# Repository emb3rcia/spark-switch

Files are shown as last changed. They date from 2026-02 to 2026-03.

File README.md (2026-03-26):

# spark-switch

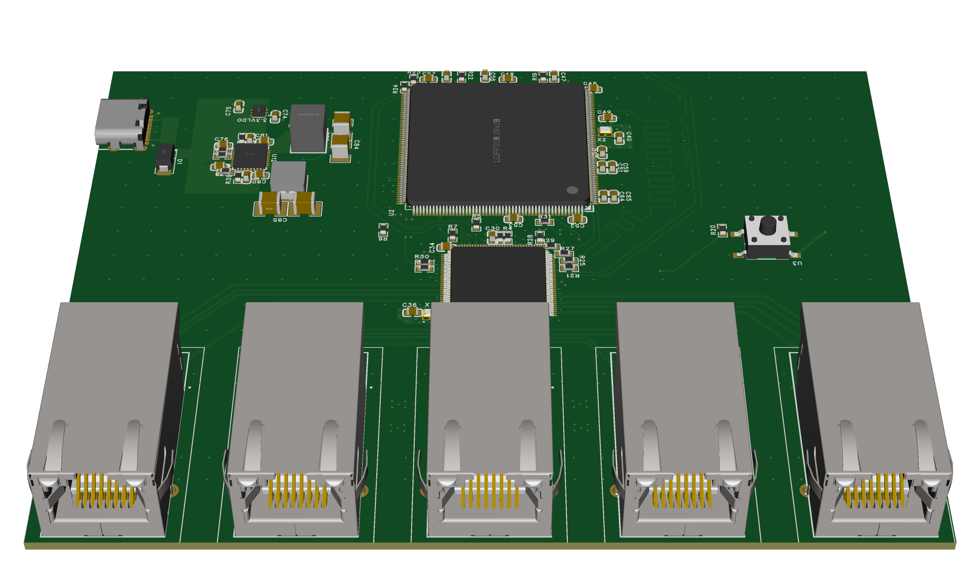
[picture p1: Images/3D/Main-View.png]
spark-switch


# Navigation
- [About project](#about-project-what-is-it)
  - [Motivation for the project](#motivation-for-the-project-why-i-made-it)
  - [Learning outcomes](#learning-outcomes-what-i-learned)
  - [Design decisions](#design-decisions)
  - [Directory overview](#directory-overview)
  - [Parts used](#parts-used)
  - [Development tools](#development-tools-tools-used)
  - [Features](#features)
  - [Block diagram](#block-diagram)
- [Documentation](#documentation)
- [Blog post](#blog-post)
- [Project status](#project-status)
- [Images](#images)
  - [2D](#2d)
  - [3D](#3d)
  - [Gerber files](#gerber-files)
- [License](#license)
  - [PCB / Schematic](#pcb--schematic-license)
  - [Software](#software-license)
  - [3D files and images](#3d-files-and-images-license)
- [Bill of Materials](#bom)

# About project (What is it)

spark-switch is 6 layer USB-C powered 5 port GbE managed Ethernet switch. It features WebUI interface for configuration and optional MQTT reporting of per-port statistics to Home Assistant (more of the features are listed [here](#features)).

It originated as a hobby project that filled my need for an Ethernet switch as well as taught me high-speed interface routing, and evolved into this fully open source Ethernet switch that is replicable by anyone and fully documented, designed for transparency.

## Motivation for the project (Why I made it)

I made this project because I love tinkering and wanted to use my need for an Ethernet switch as a way to teach myself differential pair routing. And I learned a lot from this. More information about what I learned is listed under [Learning outcomes](#learning-outcomes-what-i-learned) and information about challenges is included in [blog post](#blog-post).

## Learning outcomes (What I learned)

I learned:
- How to properly route differential pairs
- How to properly length tune traces
- How to create more readable schematics
- How to properly manage the GND plane 
- How to work with high speed interfaces

## Design decisions

- 100 Ohm differential controlled impedance for Ethernet traces
- 50 Ohm single ended controlled impedance for RMII and SPI
- Solid GND planes as reference
- 2 power planes, one split one solid
- FR4, 1.6mm thickness
- Via-In-Pad using JLCPCB's free Plated-Over Filled Via technology

## Directory overview

- Firmware project is available in `/Firmware`
- 3D case files as well as Fusion360 project files are available in `/3D`
- EasyEda Pro project files are available in `/PCB`
- Images are available in `/Images`
- Schematic PDF is available in `/Schematic`
- BOM is available in `/BOM.csv` and at the end of README
- Gerber files are available in `/Gerbers`
- Documentation is available in `/Docs`

## Parts used

- STM32F469BET6 as management microcontroller
- KSZ9477STXI as switch IC
- Bel Fuse 0826-1G1T-23-F as RJ45 ports
- ADP2116AACPZ-R7 as 2.5V and 1.2V Buck voltage converter
- TLV76733DRVR as 3.3V LDO voltage converter

## Development tools (Tools used)

- EasyEda Pro for EDA work
- Fusion360 Educational for 3D work
- STM32CubeMX, STM32CubeIDE and CLion for firmware

## Features

- Management via WebUI
- Port parameter reporting to Home Assistant via MQTT
- 5 port Ethernet switching
- GbE speeds
- Powered by USB-C (5V 3A max)
- Open-Source
- RJ45 ports with integrated magnetics

## Block diagram

Block diagram

### MCU <-> switch IC communication

Communication happens through 2 different interfaces, each with their own purpose. SPI ensures proper management of switch IC, while RMII provides connectivity required for WebUI and MQTT reporting features.

### Power

spark-switch is powered through standard USB-C 5V 2-3A connection. This decision was made to ensure easy usage of device due to its standardization across the world and availability.

Initial 5V from USB-C port is converted to 3.3V by LDO, used for MCU overall power needs and switch IC's digital interfaces, 2.5V for switch IC's core logic, and 1.2V for switch IC's PHY and analog interfaces.

# Documentation

See [docs](Docs/README.md).

# Blog post

See [this link](link-here) *Coming soon!*

# Project status

- PCB: Designed (Not tested)
- Firmware: Prototype version (Not tested)
- Docs: In work
- 3D case: Designed (Not tested)
- Blog post: Coming soon

# Images

## 2D

<details>
<summary>Click to expand 2D view images</summary>

Top view

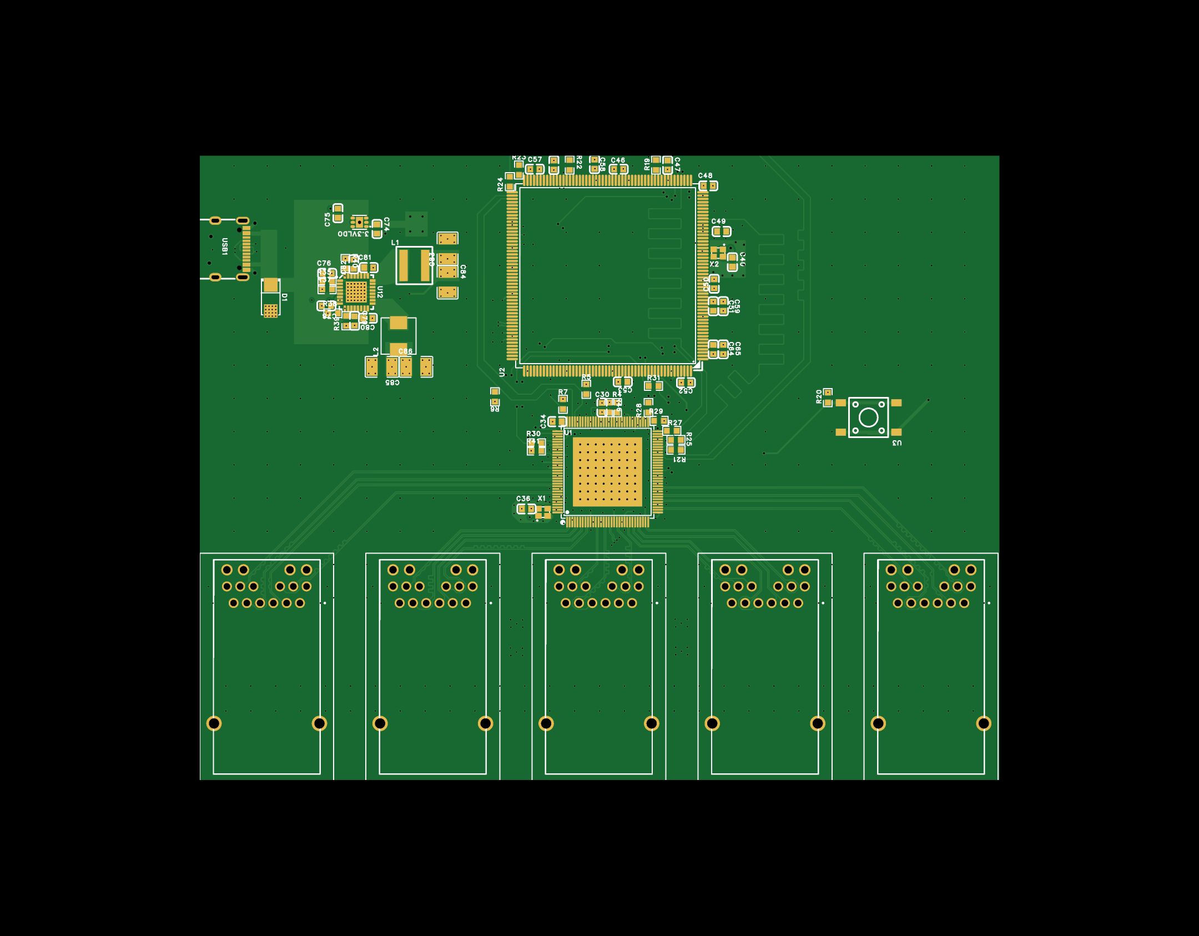
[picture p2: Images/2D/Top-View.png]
Top view


Bottom view

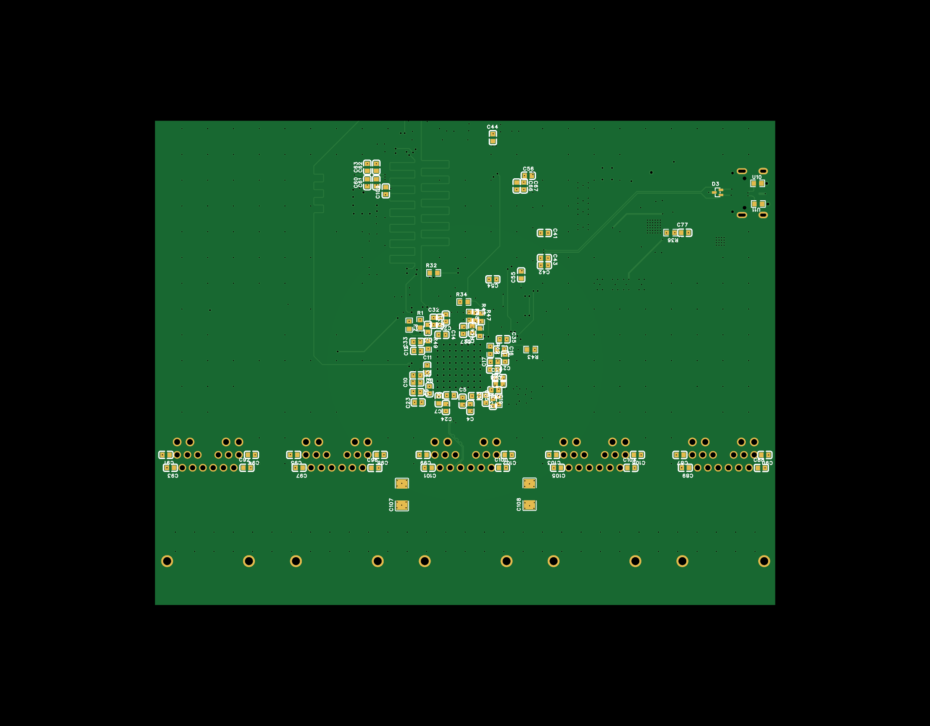
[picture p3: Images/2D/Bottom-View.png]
Top view


</details>

## 3D

<details>
<summary>Click to expand 3D view images</summary>

EasyEda Pro 3D viewer

EasyEda Pro 3D viewer

3D case + PCB

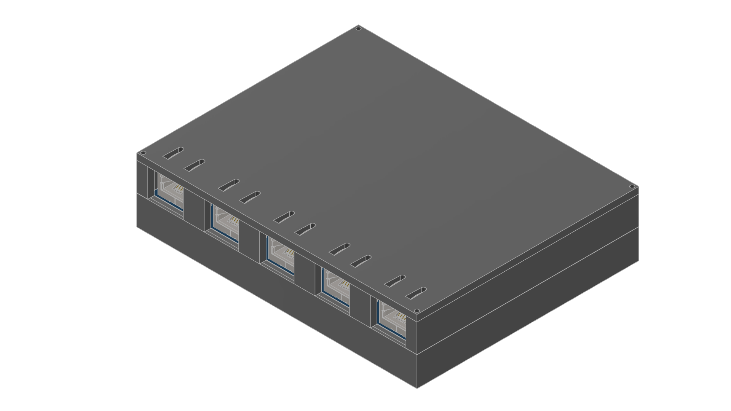
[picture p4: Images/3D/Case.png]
3D case + PCB


Top plate

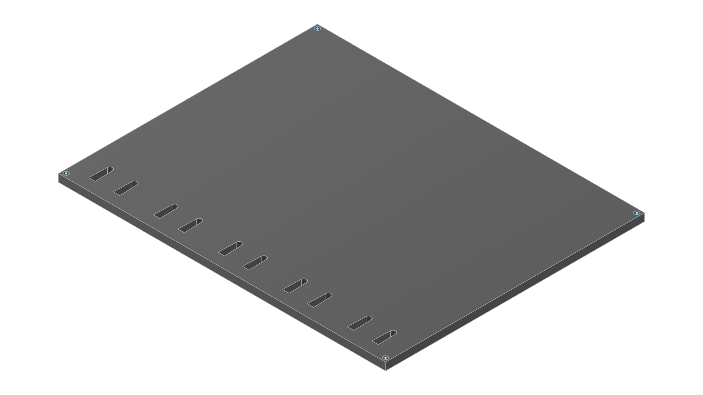
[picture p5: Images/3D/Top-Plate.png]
Top plate


Bottom case

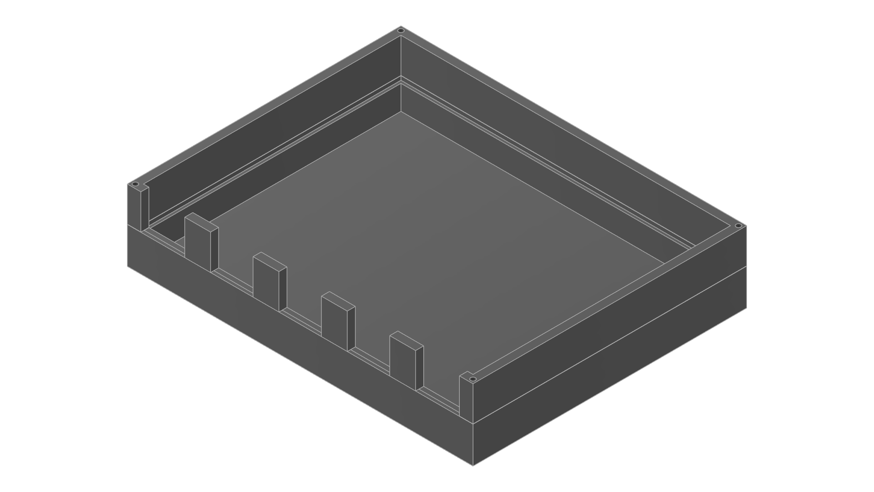
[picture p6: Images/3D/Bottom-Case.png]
Bottom case


</details>

## Gerber files

<details>
<summary>Click to expand Gerber images</summary>

Top layer view

Top layer view

Bottom layer view

Bottom layer view

Layer 1 / Top layer / Signal

Layer 1 / Top layer / Signal

Layer 2 / Inner 1 / Solid GND plane

Layer 2 / Inner 1 / Solid GND plane

Layer 3 / Inner 2 / 2.5 and 3.3V split power plane

Layer 3 / Inner 2 / 2.5 and 3.3V split power plane

Layer 4 / Inner 3 / Solid 1.2V power plane

Layer 4 / Inner 3 / Solid 1.2V power plane

Layer 5 / Inner 4 / Solid GND plane

Layer 5 / Inner 4 / Solid GND plane

Layer 6 / Bottom layer / Signal

Layer 6 / Bottom layer / Signal

</details>

# License

## PCB / Schematic License

All files in `/PCB`, `/Schematic` and `/Gerbers` folders and their subsequent subfolders are licensed under the CERN Open Hardware License v2 (Weakly Reciprocal).

See `/Licenses/CERN-OHL.txt` for full terms.

## Software License

All files in `/Firmware` folder and their subsequent subfolders are licensed under the Apache 2.0 License.

See `/Licenses/Apache-2.0.txt` for full terms.

## 3D files, images and documentation License

All files in `/3D` `/Images` and `/Docs` folders and their subsequent subfolders are licensed under the CC-BY 4.0 License.

See `/Licenses/CC-BY-4.0.txt` for full terms

# BOM

|Mouser No |Mfr. No |Manufacturer |Description |Order Qty.|Price (USD)|Ext.: (USD) |Link |
|---|---|---|---|---|---|---|---|
|504-HCM1A0503V22R2R |HCM1A0503V2-2R2-R |Eaton |Power Inductors - SMD IND MP 2.2uH 6.4A molded 2 PADS SMT |1 |$0.93 |$0.93 |https://eu.mouser.com/ProductDetail/Eaton-Electronics/HCM1A0503V2-2R2-R?qs=XeJtXLiO41RWBA51gkEp5A%3D%3D|
|704-HCM0503-3R3-R |HCM0503-3R3-R |Eaton |Power Inductors - SMD 3.3uH 6.0A |1 |$0.77 |$0.77 |https://eu.mouser.com/ProductDetail/Eaton-Electronics/HCM0503-3R3-R?qs=9HiBGwelwjteGcQzzVO1cw%3D%3D |
|708-RNAN0603BKE4K70 |RNAN0603BKE4K70 |SEI Stackpole |Thin Film Resistors - SMD 4.7KOhms 0603 25ppm Tol 0.1% High Power Alum Nitride |1 |$0.98 |$0.98 |https://eu.mouser.com/ProductDetail/SEI-Stackpole/RNAN0603BKE4K70?qs=bpu3f%2FCR1jzwNjUVb54Ifw%3D%3D |
|755-ESR03EZPD4701 |ESR03EZPD4701 |ROHM Semiconductor |Thick Film Resistors - SMD 0603 4.7Kohm 0.50% Anti Surge AEC-Q200 |1 |$0.30 |$0.30 |https://eu.mouser.com/ProductDetail/ROHM-Semiconductor/ESR03EZPD4701?qs=RLRnP5jfOJWNVmDLWgV9hw%3D%3D |
|652-CR0603FX-6041ELF|CR0603-FX-6041ELF |Bourns |Thick Film Resistors - SMD 6.04K ohm 1% |1 |$0.10 |$0.10 |https://eu.mouser.com/ProductDetail/Bourns/CR0603-FX-6041ELF?qs=0nF2VnfAjXnJh2M%2FP%252B4L9Q%3D%3D |
|652-CR0603FX-8201ELF|CR0603-FX-8201ELF |Bourns |Thick Film Resistors - SMD 8.2K ohm 1% |1 |$0.10 |$0.10 |https://eu.mouser.com/ProductDetail/Bourns/CR0603-FX-8201ELF?qs=Ody%252BWaR0NcHnKPXjxZbgSQ%3D%3D |
|667-ERJ-PA3D2702V |ERJ-PA3D2702V |Panasonic |Thick Film Resistors - SMD 0603 27Kohm 0.5% Anti-Surge AEC-Q200 |1 |$0.24 |$0.24 |https://eu.mouser.com/ProductDetail/Panasonic/ERJ-PA3D2702V?qs=BzJM0faLVqVhszn7sjlJ5A%3D%3D |
|594-MCT06030C1009FP5|MCT06030C1009FP500 |Vishay |Thin Film Resistors - SMD .1W 10ohms 1% 0603 50ppm Auto |1 |$0.10 |$0.10 |https://eu.mouser.com/ProductDetail/Vishay/MCT06030C1009FP500?qs=4DXlcry4fcXzntE6aB0o9Q%3D%3D |
|71-CRCW0603-191 |CRCW0603191RFKTA |Vishay |Thick Film Resistors - SMD 1/10watt 191ohms 1% |1 |$0.16 |$0.16 |https://eu.mouser.com/ProductDetail/Vishay/CRCW0603191RFKTA?qs=be4vbG3eqMQfmmy1Xt7ldg%3D%3D |
|279-RN73C1J1K0BTDF  |RN73C1J1K0BTDF |TE Connectivity |Thin Film Resistors - SMD RN 0603 1K0 0.1% 1 0PPM |2 |$0.68 |$1.36 |https://eu.mouser.com/ProductDetail/TE-Connectivity/RN73C1J1K0BTDF?qs=HLeXuo0aL2rjI2NxXJrhbQ%3D%3D |
|652-CR0603FX-5101ELF|CR0603-FX-5101ELF |Bourns |Thick Film Resistors - SMD 5.1K ohm 1% |2 |$0.10 |$0.20 |https://eu.mouser.com/ProductDetail/Bourns/CR0603-FX-5101ELF?qs=0nF2VnfAjXkzZl7D0jRjmQ%3D%3D |
|667-ERA-3AED303V |ERA-3AED303V |Panasonic |Thin Film Resistors - SMD 0603 30Kohms 25ppm 0.5% AEC-Q200 |2 |$0.17 |$0.34 |https://eu.mouser.com/ProductDetail/Panasonic/ERA-3AED303V?qs=yocZuyCaXdMHimFdtSiPeQ%3D%3D |
|667-ERJ-3RED33R0V |ERJ-3RED33R0V |Panasonic |Thick Film Resistors - SMD 0603 Resistor 0.5% 100ppm 33Ohm |10 |$0.142 |$1.42 |https://eu.mouser.com/ProductDetail/Panasonic/ERJ-3RED33R0V?qs=KTDjhDDUMAmaGsZIgaf5Cg%3D%3D |
|603-AC0603FRE0710KL |AC0603FRE0710KL |YAGEO |Thick Film Resistors - SMD 10 kOhms 100 mW 0603  1% AEC-Q200 Standard Power Version |16 |$0.02 |$0.32 |https://eu.mouser.com/ProductDetail/YAGEO/AC0603FRE0710KL?qs=xZ%2FP%252Ba9zWqYHurLrMYPPHg%3D%3D |
|584-ADP2116ACPZ-R7  |ADP2116ACPZ-R7 |Analog Devices Inc.|Switching Voltage Regulators Dual-Step Down Converter w/ 3A x 2output |1 |$10.36 |$10.36 |https://eu.mouser.com/ProductDetail/Analog-Devices-Inc/ADP2116ACPZ-R7?qs=WIvQP4zGanjhBnvaqIEPmA%3D%3D  |
|579-KSZ9477STXI-TR  |KSZ9477STXI-TR |Microchip |Ethernet ICs 7-Port Gigabit Ethernet Switch with Fault Recovery, 1588 v2, AVB, EEE, WOL, QoS, LinkMD+, SGMII, Industrial temp.|1 |$20.91 |$20.91 |https://eu.mouser.com/ProductDetail/Microchip/KSZ9477STXI-TR?qs=5aG0NVq1C4xvKDJXPEDvJg%3D%3D |
|947-RCLAMP0502BATCT |RCLAMP0502BATCT |Semtech |ESD Protection Diodes / TVS Diodes Low Capacitance ESD & CDE Protection |1 |$0.97 |$0.97 |https://eu.mouser.com/ProductDetail/Semtech/RCLAMP0502BATCT?qs=rBWM4%252BvDhIc%2FZh6P%252BVApRQ%3D%3D  |
|576-SMA6L5.0A |SMA6L5.0A |Littelfuse |ESD Protection Diodes / TVS Diodes 600W 5V 5% Uni-Directional |1 |$0.44 |$0.44 |https://eu.mouser.com/ProductDetail/Littelfuse/SMA6L5.0A?qs=VIHlH02q6bVPZcHxXVWyBA%3D%3D |
|511-STM32F469BET6 |STM32F469BET6 |STMicroelectronics |ARM Microcontrollers - MCU High-performance advanced line, Arm Cortex-M4 core DSP & FPU, 512 Kbytes of Flas |1 |$8.50 |$8.50 |https://eu.mouser.com/ProductDetail/STMicroelectronics/STM32F469BET6?qs=dTJS0cRn7ohWTNcv3ssTNw%3D%3D |
|595-TLV76733DRVR |TLV76733DRVR |Texas Instruments  |LDO Voltage Regulators Adjustable- and fixe d-output 1-A 16-V A A 595-TLV76733DRVT |1 |$0.94 |$0.94 |https://eu.mouser.com/ProductDetail/Texas-Instruments/TLV76733DRVR?qs=9r4v7xj2LnmGIkwTuPlHig%3D%3D |
|963-MLASJ168BB7475KT|MLASJ168BB7475KTNA01 |TAIYO YUDEN |Multilayer Ceramic Capacitors MLCC - SMD/SMT 6.3V 4.7uF X7R 0603 10% Medical |1 |$0.37 |$0.37 |https://eu.mouser.com/ProductDetail/TAIYO-YUDEN/MLASJ168BB7475KTNA01?qs=tlsG%2FOw5FFjahgohsmNLbA%3D%3D |
|603-CC0603KPX5R6B475|CC0603KPX5R6BB475 |YAGEO |Multilayer Ceramic Capacitors MLCC - SMD/SMT 10V 4.7uF X5R 0603 10% HI CV |1 |$0.211 |$0.21 |https://eu.mouser.com/ProductDetail/YAGEO/CC0603KPX5R6BB475?qs=mzRxyRlhVdtG7wG2BIZZbA%3D%3D |
|963-MLASE168AB5475KT|MLASE168AB5475KTNA01 |TAIYO YUDEN |Multilayer Ceramic Capacitors MLCC - SMD/SMT 16V 4.7uF X5R 0603 10% Medical |1 |$0.33 |$0.33 |https://eu.mouser.com/ProductDetail/TAIYO-YUDEN/MLASE168AB5475KTNA01?qs=tlsG%2FOw5FFihcKM5Bww3QA%3D%3D |
|963-BASJ168AB5106KT |MBASJ168AB5106KTNA01 |TAIYO YUDEN |Multilayer Ceramic Capacitors MLCC - SMD/SMT 6.3V 10uF X5R 0603 10% Industrial |1 |$0.17 |$0.17 |https://eu.mouser.com/ProductDetail/TAIYO-YUDEN/MBASJ168AB5106KTNA01?qs=tlsG%2FOw5FFip7wSSy5q9Rw%3D%3D |
|963-MLASL168BB5106MT|MLASL168BB5106MTNB33 |TAIYO YUDEN |Multilayer Ceramic Capacitors MLCC - SMD/SMT 10V 10uF X5R 0603 20% |1 |$0.17 |$0.17 |https://eu.mouser.com/ProductDetail/TAIYO-YUDEN/MLASL168BB5106MTNB33?qs=tlsG%2FOw5FFiv4vsvq7EGpg%3D%3D |
|963-MAASE32MSB7226MP|MAASE32MSB7226MPNA01 |TAIYO YUDEN |Multilayer Ceramic Capacitors MLCC - SMD/SMT 1210 16V X7R 22uF 20% AEC-Q200 |1 |$0.661 |$0.66 |https://eu.mouser.com/ProductDetail/TAIYO-YUDEN/MAASE32MSB7226MPNA01?qs=FmjOKN4Os86zaasSFxugIA%3D%3D |
|581-12101C104M |12101C104MAT2A |KYOCERA AVX |Multilayer Ceramic Capacitors MLCC - SMD/SMT KGM32RR72A104MU NEW GLOBAL PN 100V 0.1uF A 581-KGM32RR72A104MU |1 |$0.22 |$0.22 |https://eu.mouser.com/ProductDetail/KYOCERA-AVX/12101C104MAT2A?qs=FWPE8OmxvdQRu%2FvuFEOTRw%3D%3D |
|81-GR442QR73D102KW01|GR442QR73D102KW01L |Murata |Multilayer Ceramic Capacitors MLCC - SMD/SMT 1000 pF 2 kVDC 10% 1808 X7R |2 |$0.59 |$1.18 |https://eu.mouser.com/ProductDetail/Murata/GR442QR73D102KW01L?qs=1XGAtBqYNz74JcxvF1DQuw%3D%3D |
|581-KGM15BR50J225KT |KGM15BR50J225KT |KYOCERA AVX |Multilayer Ceramic Capacitors MLCC - SMD/SMT 6.3V 2.2uF X5R 0603 10% |2 |$0.17 |$0.34 |https://eu.mouser.com/ProductDetail/KYOCERA-AVX/KGM15BR50J225KT?qs=Jm2GQyTW%2FbgTJAmtR1rY5w%3D%3D |
|963-MAASL32MSB7476MP|MAASL32MSB7476MPNA01 |TAIYO YUDEN |Multilayer Ceramic Capacitors MLCC - SMD/SMT 1210 10V X7R 47uF 20% AEC-Q200 |1 |$0.83 |$0.83 |https://eu.mouser.com/ProductDetail/TAIYO-YUDEN/MAASL32MSB7476MPNA01?qs=FmjOKN4Os87n4oCsWJehZg%3D%3D |
|581-06035C821JAZ2A  |06035C821JAZ2A |KYOCERA AVX |Multilayer Ceramic Capacitors MLCC - SMD/SMT 50V 820pF X7R 0603 5 % Tol FLEX |2 |$0.34 |$0.68 |https://eu.mouser.com/ProductDetail/KYOCERA-AVX/06035C821JAZ2A?qs=zKGwLYtK3Ltn1p%252BM3OK9xQ%3D%3D |
|81-GRM188C81A226ME1D|GRM188C81A226ME01D |Murata |Multilayer Ceramic Capacitors MLCC - SMD/SMT 0603 10VDC 22uF 20% X6S |3 |$0.40 |$1.20 |https://eu.mouser.com/ProductDetail/Murata/GRM188C81A226ME01D?qs=doiCPypUmgGpyx8gzUcykQ%3D%3D |
|581-06035A103JAT2A  |06035A103JAT2A |KYOCERA AVX |Multilayer Ceramic Capacitors MLCC - SMD/SMT .01UF 50V 5% 0603 |4 |$0.33 |$1.32 |https://eu.mouser.com/ProductDetail/KYOCERA-AVX/06035A103JAT2A?qs=Cw3yY7soYCOJ7MBOLgA8ng%3D%3D |
|581-KGM15BS60J105KT |KGM15BS60J105KT |KYOCERA AVX |Multilayer Ceramic Capacitors MLCC - SMD/SMT 6.3V 1uF X6S 0603 10% |6 |$0.12 |$0.72 |https://eu.mouser.com/ProductDetail/KYOCERA-AVX/KGM15BS60J105KT?qs=PBDs2xEllI9EnrKjYPal4Q%3D%3D |
|603-CC603JRX7R9BB104|CC0603JRX7R9BB104 |YAGEO |Multilayer Ceramic Capacitors MLCC - SMD/SMT 50 V 0.1uF X7R 0603 5% |73 |$0.035 |$2.56 |https://eu.mouser.com/ProductDetail/YAGEO/CC0603JRX7R9BB104?qs=57cj7OiSijmjSM%252BQadQODQ%3D%3D |
|520-2016MV-250-BNT  |ECS-2016MV-250-BN-TR |ECS |Standard Clock Oscillators 25MHz CMOS 1.6-3.6V |2 |$1.63 |$3.26 |https://eu.mouser.com/ProductDetail/ECS/ECS-2016MV-250-BN-TR?qs=MLItCLRbWszJuavuZB87ww%3D%3D |
|530-0826-1G1T-23-F  |0826-1G1T-23-F |Bel |Modular Connectors / Ethernet Connectors RJ45 Connector |5 |$7.35 |$36.75 |https://eu.mouser.com/ProductDetail/Bel/0826-1G1T-23-F?qs=SRYZG9HaIQ0yqJ%252BCqOsSRg%3D%3D |
|N/A |TS6643TP 250gf 009 |Shou Han |Boot button |0 |0 |0 |https://www.lcsc.com/product-detail/C5342967.html |
|N/A |TYPE-C 16PIN 2MD(073)|Shou Han |USB-C Port |0 |0 |0 |https://www.lcsc.com/product-detail/C2765186.html |
|N/A |N/A |JLCPCB |PCB |5 |$84.99 |$84.99 + $7.90 shipping|https://jlcpcb.com |
|N/A |N/A |JLCPCB |Stencil |1 |$7.11 |$7.11 |https://jlcpcb.com |
| | | | | |Total |$200.41 | |

© 2026 emb3rcia

Firmware: Apache 2.0
Hardware: CERN OHL v2
3D & Images: CC BY 4.0

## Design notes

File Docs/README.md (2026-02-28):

# Navigation

- [Hardware](/Hardware.md)
- [Firmware](/Firmware.md)
- [Features](/Features.md)
- [3D case](/3D-case.md)

# License

Files in this and any subsequent folders are licensed under CC-BY 4.0 License.
See [here](../README.md#license) for more information.

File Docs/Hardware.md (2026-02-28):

# Hardware

## Parts

- STM32F469BET6 as management microcontroller
- KSZ9477STXI as switch IC
- Bel Fuse 0826-1G1T-23-F as RJ45 ports
- ADP2116AACPZ-R7 as 2.5V and 1.2V Buck voltage converter
- TLV76733DRVR as 3.3V LDO voltage converter

## Generic parts

There are many parts that wasn't listed above because they are too general to give specific part number. These parts include but are not limited to capacitors, inductors or resistors. For full part list needed, look into Basket of Materials either at the end of [main README.md](../README.md) or in [BOM.csv](../BOM.csv) and match individual part parameters to part of your choice.

## PCB

spark-switch uses standard 6 layer 1.6mm FR4 PCB. Stackup is JLCPCB's JLC06161H-3313.

## Hand-soldering possibility

Although most parts are chosen with hand soldering in mind (eg most passives being 0603 size), there are components with exposed pads that are impossible to solder with only soldering iron. If you want to chose hand soldering while replicating this project, consider using hot air or reflow oven for these components, or if you are unable to, consider choosing PCB Assembly for them.

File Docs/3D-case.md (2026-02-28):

# 3D case

3D case is designed to be 3D printed from easy to print materials like PLA or PETG.

## Screws

3D case takes standard M2x12 Screws. Holes are made without countersink and are 13 mm deep for extra safety room and 1.8 mm wide for screw to thread itself into the plastic. If you plan on using metal case with this project, you need to adjust screw hole size.

## Images

3D case + PCB

3D case + PCB

Top plate

Top plate

Bottom case

Bottom case

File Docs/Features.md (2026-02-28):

# Features

Features of spark-switch include:

- Management via WebUI
- Port parameter reporting to Home Assistant via MQTT
- 5 port Ethernet switching
- GbE speeds
- Powered by USB-C (5V 3A max)
- Open-Source
- RJ45 ports with integrated magnetics

## WebUI

As stated in [firmware section of docs](./Firmware.md), any part of it is not final, and docs for them will be provided with first proper firmware commit.

## Home Assistant reporting

See above.

## Power

spark-switch was designed with power via standard USB-C at 5V 2-3A power. It is ensured by using 2 5.1kOhm resistors at CC pins of USB-C port connected to ground. USB-C is the only supported and available option to power spark-switch

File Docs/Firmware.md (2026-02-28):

# Firmware

# Disclaimer

Current firmware is not final and is subject to fundamental changes. It is requirement to provide one in repository per YSWS event's rules that this project is made for and was written as prototype, with full rewrite after PCB assembly in mind. Because of this, firmware section of docs will be provided with first proper firmware commit.

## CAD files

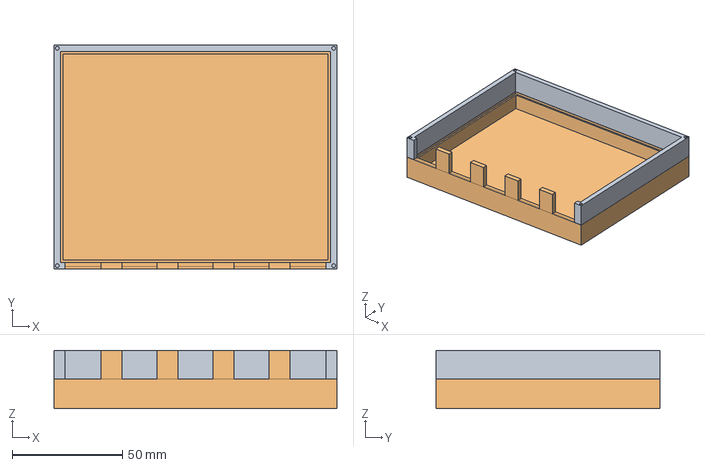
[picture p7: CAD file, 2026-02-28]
3D/STEP/bottom_plate.step
128.5 x 101.7 x 26.5 mm

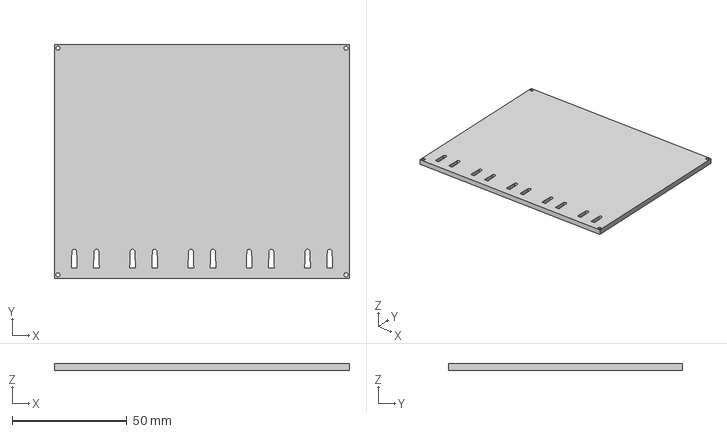
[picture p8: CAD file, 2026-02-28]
3D/STEP/top_plate.step
128.5 x 101.7 x 3.00 mm

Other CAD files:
3D/Fusion 360/bottom_plate.f3d
3D/Fusion 360/top_plate.f3d

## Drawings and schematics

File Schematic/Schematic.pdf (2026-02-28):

# RJ45 Ports

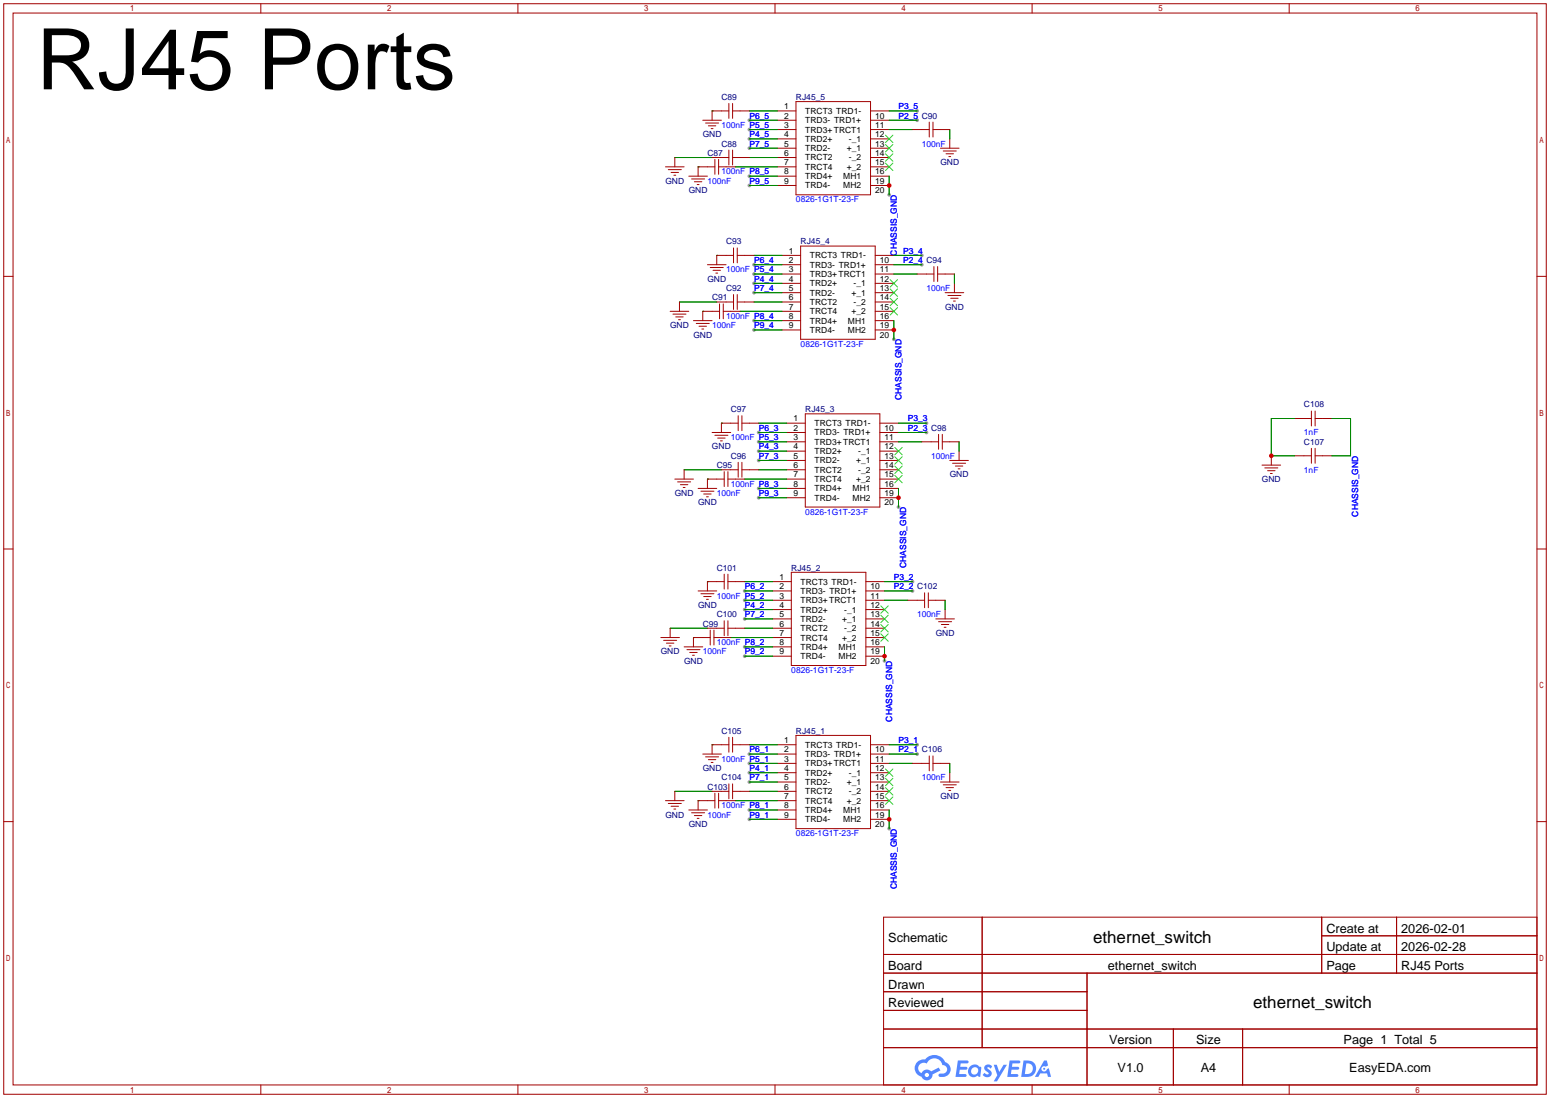
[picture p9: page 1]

Schematic | ethernet_switch | Create at | 2026-02-01

Update at | 2026-02-28

Board | ethernet_switch | Page | RJ45 Ports
Drawn | | ethernet_switch
Reviewed

Version | Size | Page 1 Total 5
V1.0 | A4 | EasyEDA.com

Switch IC | OE/NC

# Strap configuration

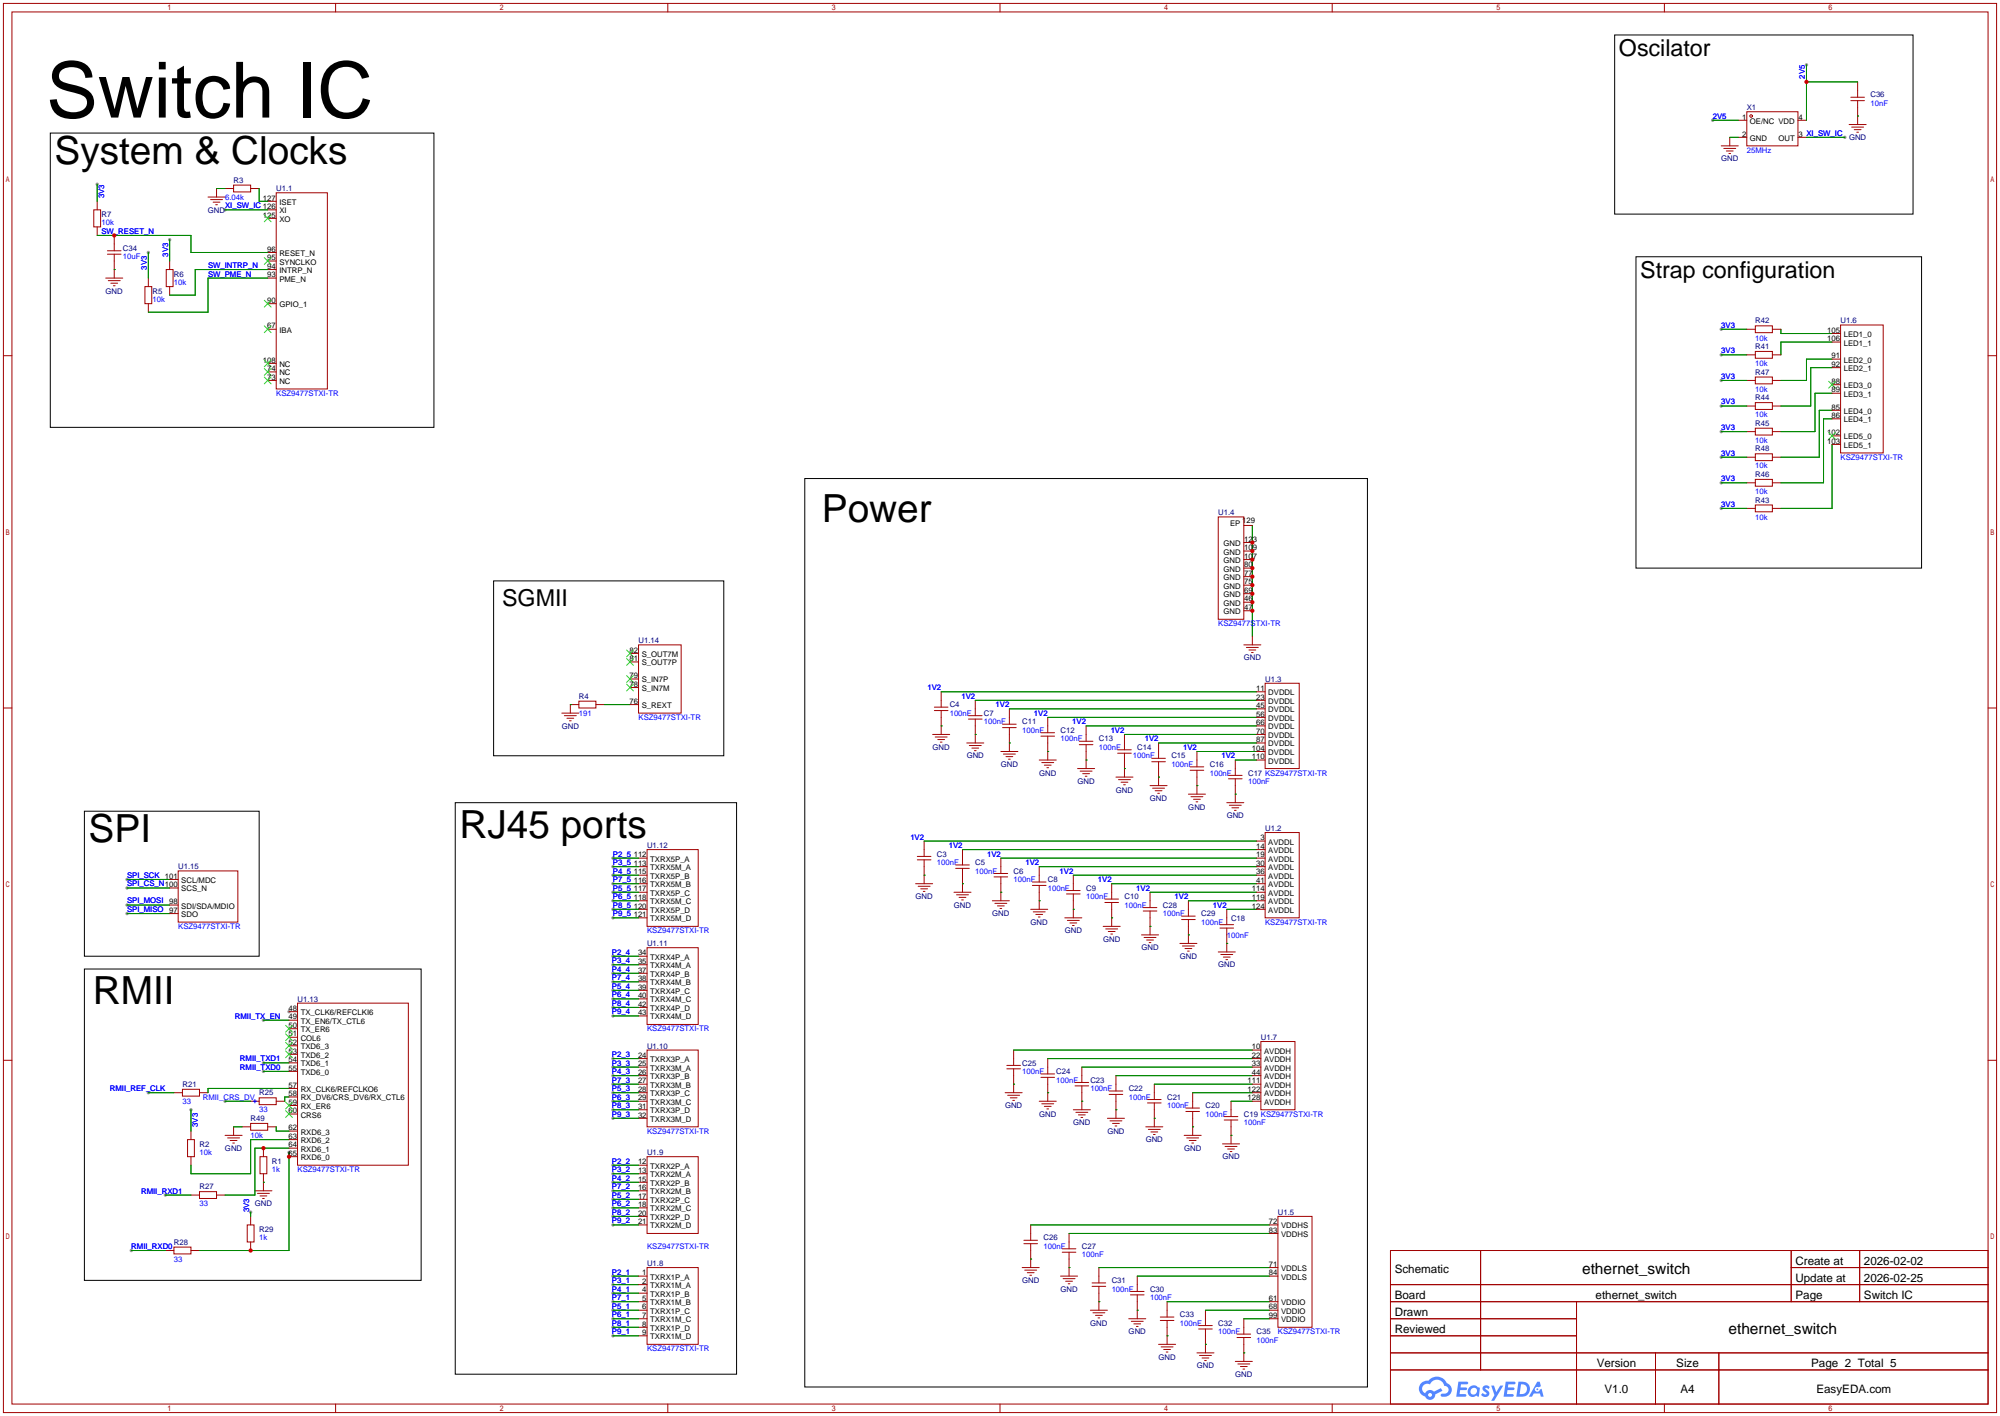
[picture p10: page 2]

Schematic | ethernet_switch | Create at | 2026-02-02

Update at | 2026-02-25

Board | ethernet_switch | Page | Switch IC
Drawn | | ethernet_switch
Reviewed

PA13 147 PA12 146 PA11 145 PA10 144 PA9 143 PA8 142 PA7 56 PA6 55 PA5 54 PA4 53 PA3 50 PA2 45 PA1 44 PA0 43

PC12 163 PC11 162 PC10 161 PC9 141 PC8 140 PC7 139 PC6 138 PC5 58 PC4 57 PC3 38 PC2 37 PC1 36 PC0 35

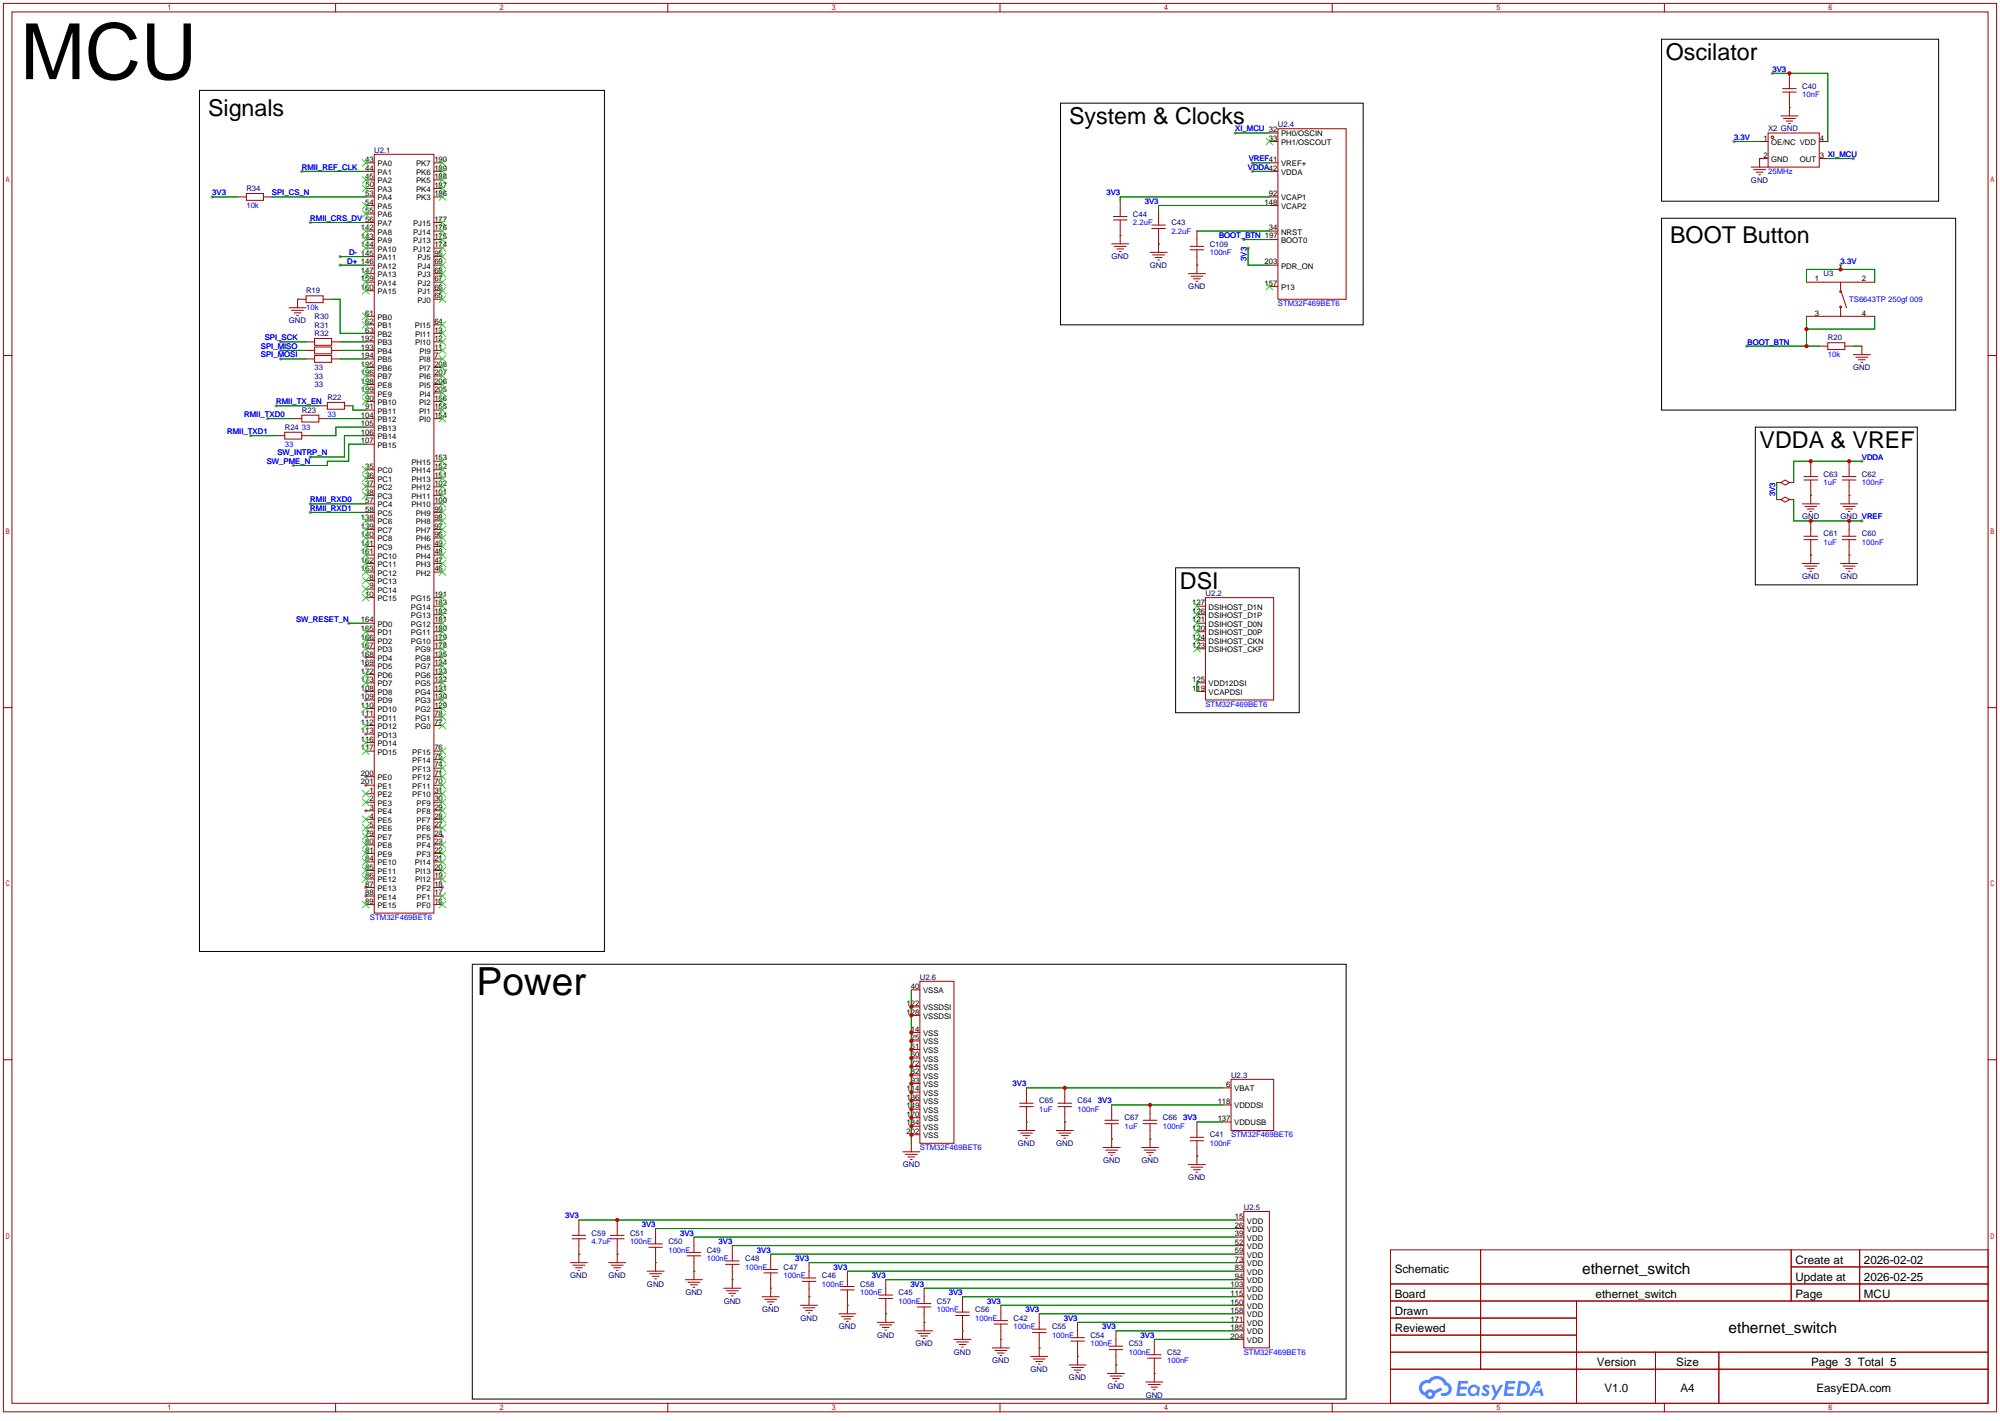
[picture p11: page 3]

VSS 25 VSS 14
VSS 114 VSS 93 VSS 82 VSS 72 VSS 60 VSS 51

VSS 202 VSS 184 VSS 170 VSS 149 VSS 136

Schematic | ethernet_switch | Create at | 2026-02-02

Update at | 2026-02-25

Board | ethernet_switch | Page | MCU
Drawn | | ethernet_switch
Reviewed

Version | Size | Page 3 Total 5
V1.0 | A4 | EasyEDA.com

# LDO and Buck

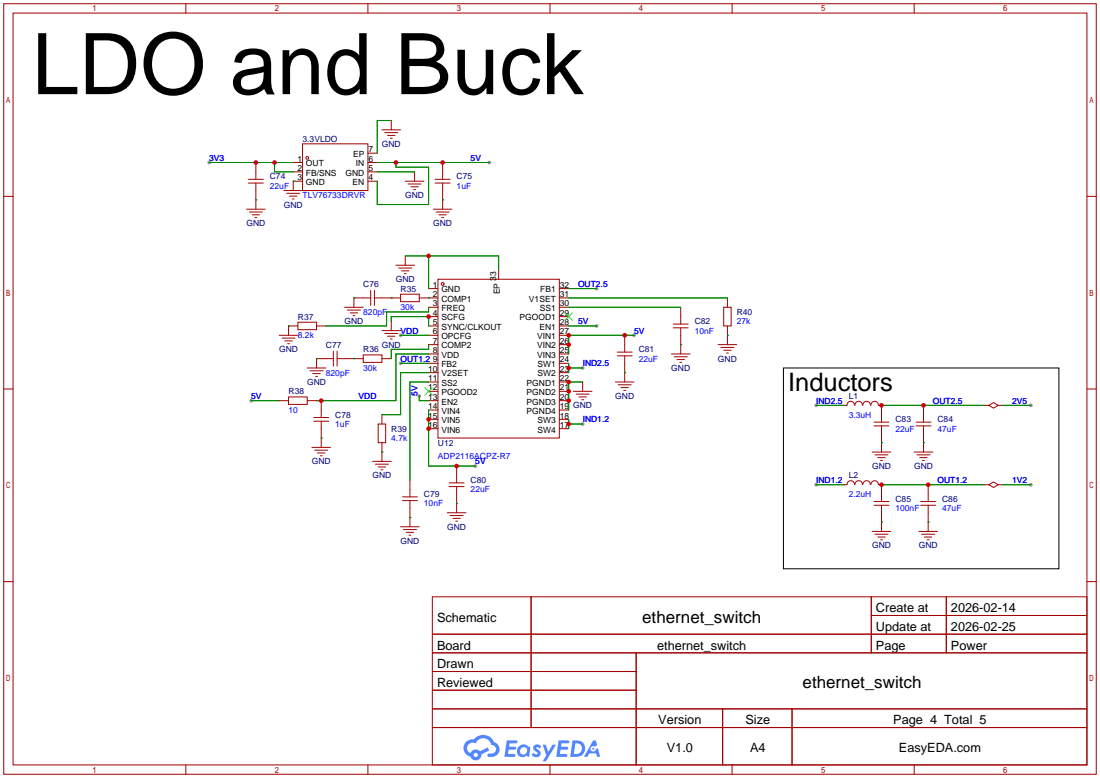
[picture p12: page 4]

Schematic | ethernet_switch | Create at | 2026-02-14

Update at | 2026-02-25

Board | ethernet_switch | Page | Power
Drawn | | ethernet_switch
Reviewed

# USB + ESD

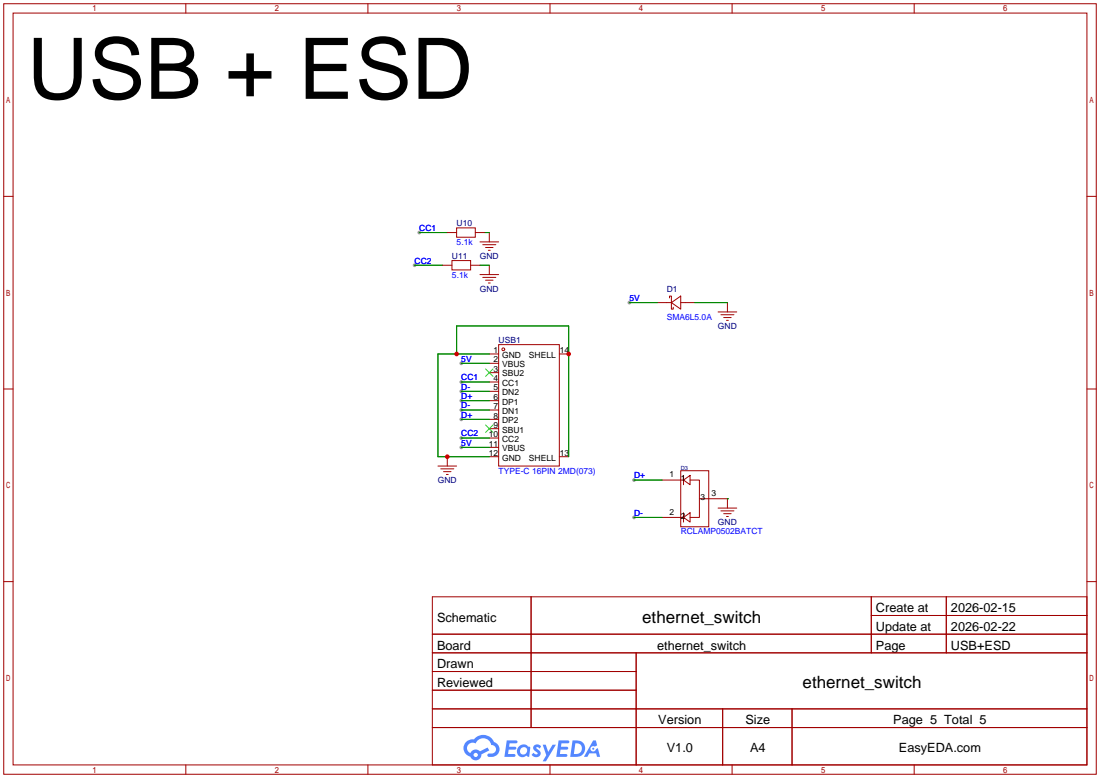
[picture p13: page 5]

Schematic | ethernet_switch | Create at | 2026-02-15

Update at | 2026-02-22

Board | ethernet_switch | Page | USB+ESD
Drawn | | ethernet_switch
Reviewed

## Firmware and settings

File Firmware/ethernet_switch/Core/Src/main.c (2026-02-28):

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
/* Includes ------------------------------------------------------------------*/
#include "main.h"
#include "cmsis_os.h"
#include "lwip.h"
#include "usb_device.h"

/* USER CODE BEGIN Includes */
#include "kszspi.h"
#include "config.h"
/* USER CODE END Includes */

/* USER CODE BEGIN PD */
#define MIB_RX_BYTE_CNT 0x80
#define MIB_TX_BYTE_CNT 0x81
/* USER CODE END PD */

SPI_HandleTypeDef hspi1;
DMA_HandleTypeDef hdma_spi1_tx;
DMA_HandleTypeDef hdma_spi1_rx;

osThreadId MainTaskHandle;
osThreadId WebUITaskHandle;
osThreadId MQTTTaskHandle;
osMessageQId mqttPublishQueueHandle;
void SystemClock_Config(void);
static void MX_GPIO_Init(void);
static void MX_DMA_Init(void);
static void MX_SPI1_Init(void);
void StartDefaultTask(void const * argument);
void StartTask02(void const * argument);
void StartTask03(void const * argument);

/**
  * @brief  The application entry point.
  * @retval int
  */
int main(void)
{

  /* MCU Configuration--------------------------------------------------------*/

  /* Reset of all peripherals, Initializes the Flash interface and the Systick. */
  HAL_Init();

  /* Configure the system clock */
  SystemClock_Config();

  /* Initialize all configured peripherals */
  MX_GPIO_Init();
  MX_DMA_Init();
  MX_SPI1_Init();
  /* USER CODE BEGIN 2 */
  Config_Init();
  /* USER CODE END 2 */

  /* USER CODE BEGIN RTOS_MUTEX */
  /* add mutexes, ... */
  /* USER CODE END RTOS_MUTEX */

  /* USER CODE BEGIN RTOS_SEMAPHORES */
  /* add semaphores, ... */
  /* USER CODE END RTOS_SEMAPHORES */

  /* USER CODE BEGIN RTOS_TIMERS */
  /* start timers, add new ones, ... */
  /* USER CODE END RTOS_TIMERS */

  /* Create the queue(s) */
  /* definition and creation of mqttPublishQueue */
  osMessageQDef(mqttPublishQueue, 16, uint32_t);
  mqttPublishQueueHandle = osMessageCreate(osMessageQ(mqttPublishQueue), NULL);

  /* USER CODE BEGIN RTOS_QUEUES */
  /* add queues, ... */
  /* USER CODE END RTOS_QUEUES */

  /* Create the thread(s) */
  /* definition and creation of MainTask */
  osThreadDef(MainTask, StartDefaultTask, osPriorityNormal, 0, 256);
  MainTaskHandle = osThreadCreate(osThread(MainTask), NULL);

  /* definition and creation of WebUITask */
  osThreadDef(WebUITask, StartTask02, osPriorityIdle, 0, 1024);
  WebUITaskHandle = osThreadCreate(osThread(WebUITask), NULL);

  /* definition and creation of MQTTTask */
  osThreadDef(MQTTTask, StartTask03, osPriorityIdle, 0, 2048);
  MQTTTaskHandle = osThreadCreate(osThread(MQTTTask), NULL);

  /* USER CODE BEGIN RTOS_THREADS */
  /* add threads, ... */
  /* USER CODE END RTOS_THREADS */

  /* Start scheduler */
  osKernelStart();

  /* We should never get here as control is now taken by the scheduler */

  /* Infinite loop */
  /* USER CODE BEGIN WHILE */
  while (1)
  {
    /* USER CODE END WHILE */

    /* USER CODE BEGIN 3 */
  }
  /* USER CODE END 3 */
}

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
/* USER CODE BEGIN Header_StartDefaultTask */
/**
  * @brief  Function implementing the MainTask thread.
  * @param  argument: Not used
  * @retval None
  */
/* USER CODE END Header_StartDefaultTask */
void StartDefaultTask(void const * argument)
{
  /* init code for USB_DEVICE */
  MX_USB_DEVICE_Init();

  /* init code for LWIP */
  MX_LWIP_Init();
  /* USER CODE BEGIN 5 */
  if (KSZ_SPI_Init() == 1) {

  } else {

  }

  uint16_t speed = 0;
  uint8_t duplex = 0;
  uint8_t link_status = 0;
  uint64_t rx_bytes = 0;
  uint64_t tx_bytes = 0;

  /* Infinite loop */
  for(;;)
  {

    char *json_buffer = (char *)pvPortMalloc(512);

    if (json_buffer != NULL) {
      int offset = 0;

      offset += snprintf(json_buffer + offset, sizeof(json_buffer) - offset, "{");

      for (int i = 1; i < 8; i++) {
        link_status = KSZ_GetPortStatus(i, &speed, &duplex);
        if (link_status == 1) {
          rx_bytes = KSZ_ReadMIB(i, MIB_RX_BYTE_CNT);
          tx_bytes = KSZ_ReadMIB(i, MIB_TX_BYTE_CNT);
        } else {
          rx_bytes = 0;
          tx_bytes = 0;
        }
        offset += snprintf(json_buffer + offset, sizeof(json_buffer) - offset,
                     "\"port_%d\":{\"link\":%d,\"speed\":%d,\"duplex\":%d,\"rx\":%llu,\"tx\":%llu}%s",
                     i, link_status, speed, duplex, rx_bytes, tx_bytes,
                     (i == 7) ? "" : ",");
      }
      snprintf(json_buffer + offset, sizeof(json_buffer) - offset, "}");

      char *pointer_to_send = json_buffer;

      if (xQueueSend(mqttPublishQueueHandle, &json_buffer, pdMS_TO_TICKS(10)) != pdPASS) {
        vPortFree(json_buffer);
      }
    }

    osDelay(1000);
  }
  /* USER CODE END 5 */
}

/* USER CODE BEGIN Header_StartTask02 */
/**
* @brief Function implementing the WebUITask thread.
* @param argument: Not used
* @retval None
*/
/* USER CODE END Header_StartTask02 */
void StartTask02(void const * argument)
{
  /* USER CODE BEGIN StartTask02 */
  /* Infinite loop */
  for(;;)
  {
    osDelay(1);
  }
  /* USER CODE END StartTask02 */
}

/* USER CODE BEGIN Header_StartTask03 */
/**
* @brief Function implementing the MQTTTask thread.
* @param argument: Not used
* @retval None
*/
/* USER CODE END Header_StartTask03 */
void StartTask03(void const * argument)
{
  /* USER CODE BEGIN StartTask03 */
  mqtt_client_t *client = mqtt_client_new();

  ip_addr_t broker_ip;
  struct mqtt_connect_client_info_t ci;

  memset(&ci, 0, sizeof(ci));
  ci.client_id = "stm32_switch";
  ci.keep_alive = 60;

  char *received_json = NULL;

  /* Infinite loop */
  for(;;)
  {
    if (xQueueReceive(mqttPublishQueueHandle, &received_json, portMAX_DELAY) == pdPASS)
    {
      if (client != NULL) {
        ipaddr_aton(CurrentConfig.mqtt_broker_ip, &broker_ip);
        if (!mqtt_client_is_connected(client)) {
          mqtt_client_connect(client, &broker_ip, 1883, NULL, NULL, &ci);

          osDelay(200);
        }

        if (mqtt_client_is_connected(client))
        {
          mqtt_publish(client,
                       "homeassistant/sensor/ksz9477/state",
                       received_json,
                       strlen(received_json),
                       0, 0, NULL, NULL);
        }
      }

      vPortFree(received_json);
    }
  }
  /* USER CODE END StartTask03 */
}

/**
  * @brief  Period elapsed callback in non blocking mode
  * @note   This function is called  when TIM6 interrupt took place, inside
  * HAL_TIM_IRQHandler(). It makes a direct call to HAL_IncTick() to increment
  * a global variable "uwTick" used as application time base.
  * @param  htim : TIM handle
  * @retval None
  */
void HAL_TIM_PeriodElapsedCallback(TIM_HandleTypeDef *htim)
{
  if (htim->Instance == TIM6)
  {
    HAL_IncTick();
  }
}

/**
  * @brief  This function is executed in case of error occurrence.
  * @retval None
  */
void Error_Handler(void)
{
  /* USER CODE BEGIN Error_Handler_Debug */
  /* User can add his own implementation to report the HAL error return state */
  __disable_irq();
  while (1)
  {
  }
  /* USER CODE END Error_Handler_Debug */
}
#ifdef USE_FULL_ASSERT
/**
  * @brief  Reports the name of the source file and the source line number
  *         where the assert_param error has occurred.
  * @param  file: pointer to the source file name
  * @param  line: assert_param error line source number
  * @retval None
  */
void assert_failed(uint8_t *file, uint32_t line)
{
  /* USER CODE BEGIN 6 */
  /* User can add his own implementation to report the file name and line number,
     ex: printf("Wrong parameters value: file %s on line %d\r\n", file, line) */
  /* USER CODE END 6 */
}
#endif /* USE_FULL_ASSERT */

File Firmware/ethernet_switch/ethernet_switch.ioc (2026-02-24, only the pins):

Mcu.UserName=STM32F469BETx
PA1.Signal=ETH_REF_CLK
PA2.Signal=ETH_MDIO
PA4.GPIO_Label=ETH_CS
PA4.Signal=GPIO_Output
PA7.Signal=ETH_CRS_DV
PB11.Signal=ETH_TX_EN
PB12.Signal=ETH_TXD0
PB13.Signal=ETH_TXD1
PB14.GPIO_Label=ETH_INT
PB14.Signal=GPXTI14
PB15.GPIO_Label=ETH_PME
PB15.Signal=GPIO_Input
PB3.Signal=SPI1_SCK
PB4.Signal=SPI1_MISO
PB5.Signal=SPI1_MOSI
PC1.Signal=ETH_MDC
PC4.Signal=ETH_RXD0
PC5.Signal=ETH_RXD1
PD0.GPIO_Label=ETH_RST
PD0.Signal=GPIO_Output

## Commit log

2026-02-25 Improved readme.md, added gerbers, bom, schematic pdf and project files
    [BOM.csv]
2026-02-28 Temp branch - transfering files from windows to linux
    [bottom_plate.f3d, bottom_plate.step, top_plate.f3d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]
2026-02-28 Refined README.md. Added prototype firmware in whole. Added 3D case. Made documentation
2026-02-28 Changer lcsc to mouser
    [BOM.csv]
2026-02-28 Minor fix
    [BOM.csv]

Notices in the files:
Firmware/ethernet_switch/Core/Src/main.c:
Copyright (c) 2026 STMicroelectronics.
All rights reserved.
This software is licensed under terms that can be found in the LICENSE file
